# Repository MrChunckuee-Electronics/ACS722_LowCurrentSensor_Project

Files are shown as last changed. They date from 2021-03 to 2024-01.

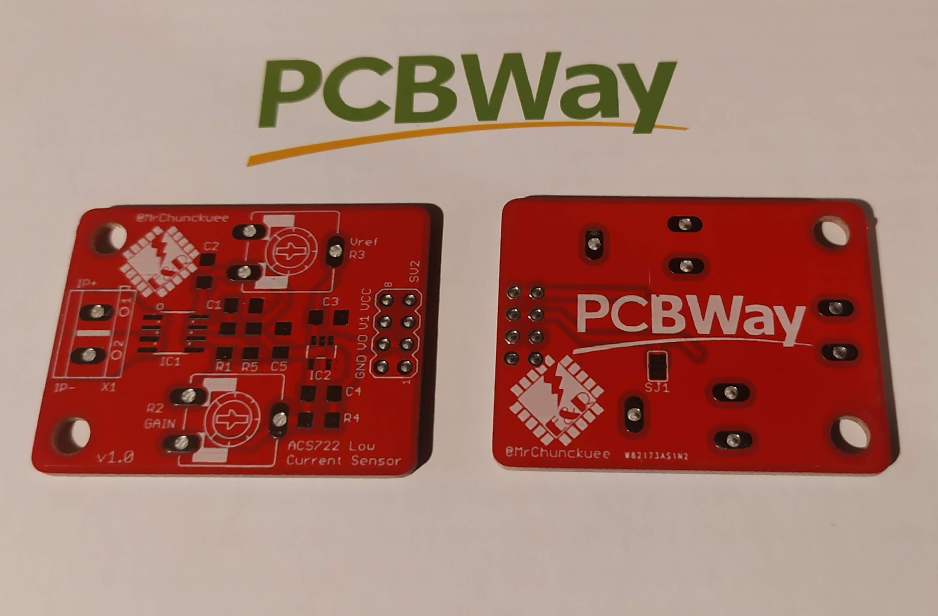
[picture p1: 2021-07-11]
assets/6 ACS722_Low_Current_Sensor_Photo1.jpg

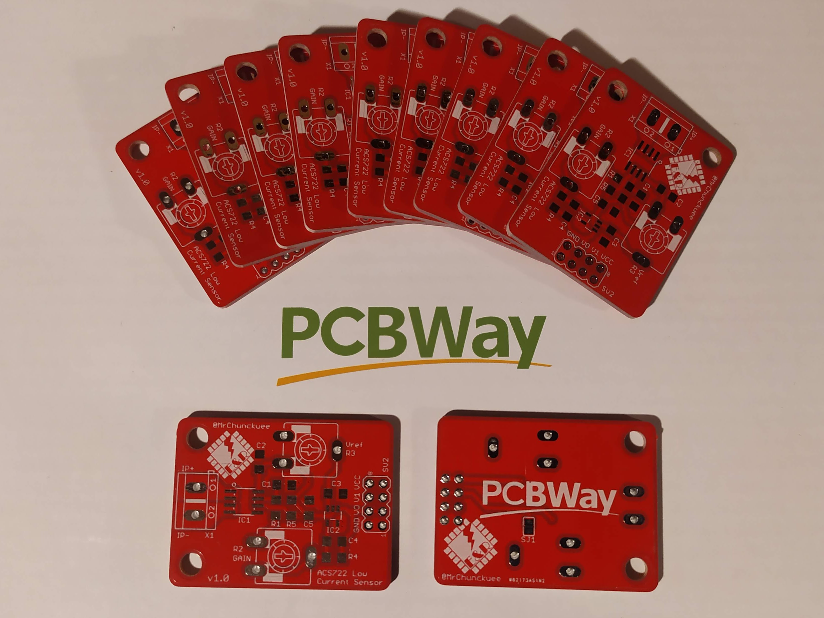
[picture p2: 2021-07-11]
assets/7 ACS722_Low_Current_Sensor_Photo2.jpg

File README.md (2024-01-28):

# ACS722 Low Current Sensor Project

***
Puedes seguirme en:
- [Blogspot](http://mrchunckuee.blogspot.com)
- [Instagram](https://www.instagram.com/mrchunckuee_electronics/)
- [Facebook](https://www.facebook.com/MrChunckueeElectronics)
- [Twitter](https://twitter.com/MrChunckuee)
- [YouTube](https://www.youtube.com/@MrChunckueeElectronics)

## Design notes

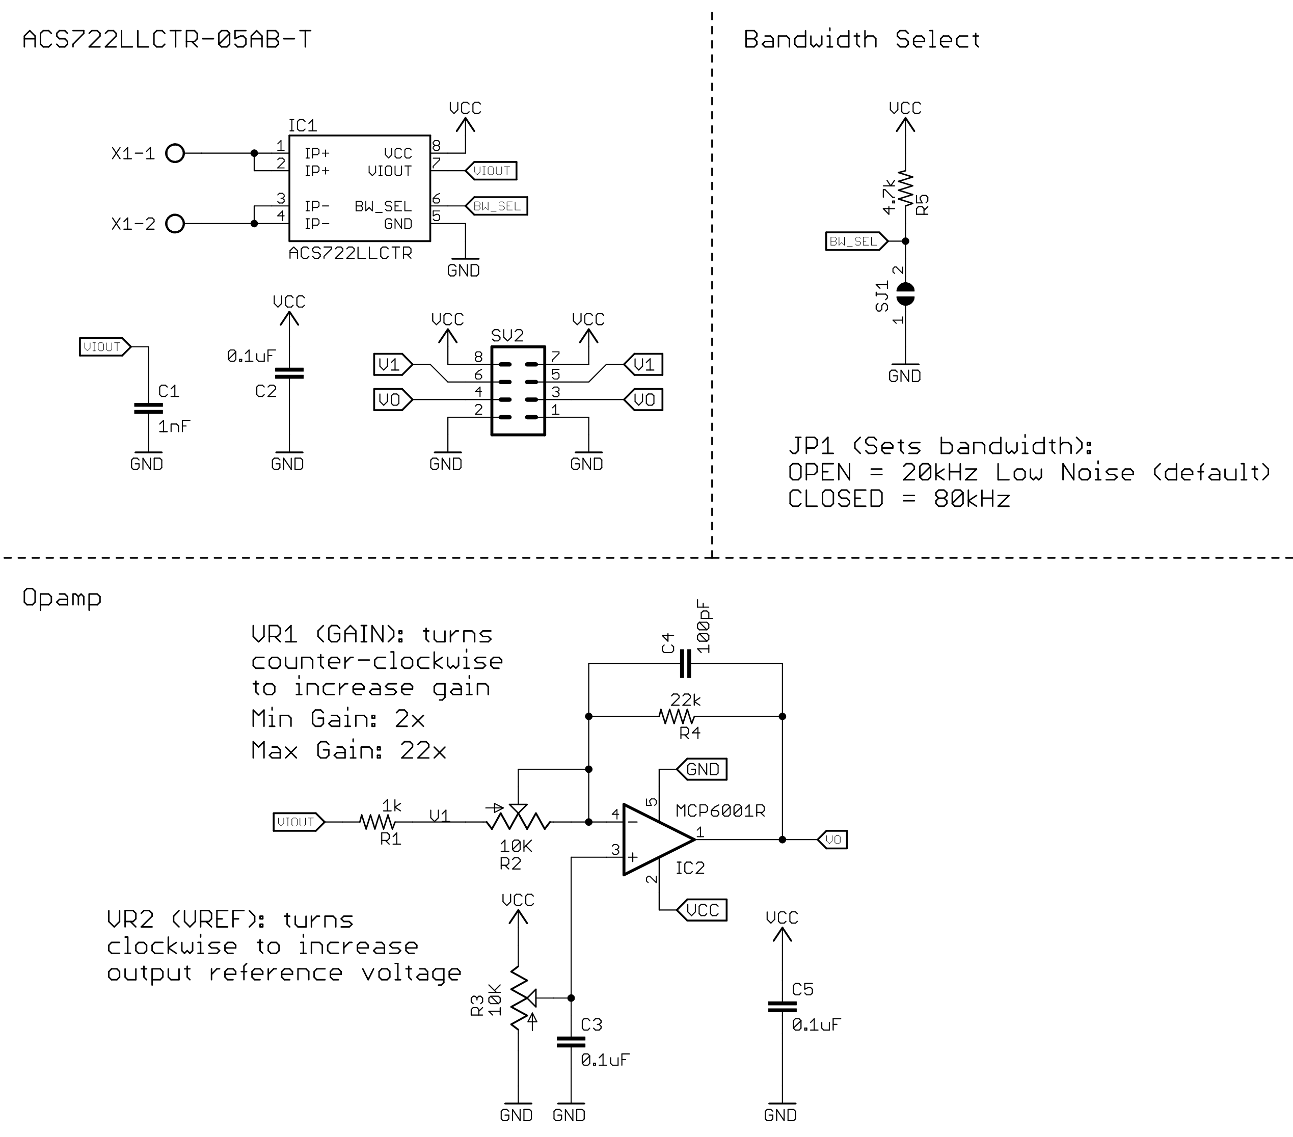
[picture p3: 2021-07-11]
assets/0 ACS722_Low_Current_Sensor_Schematic.png

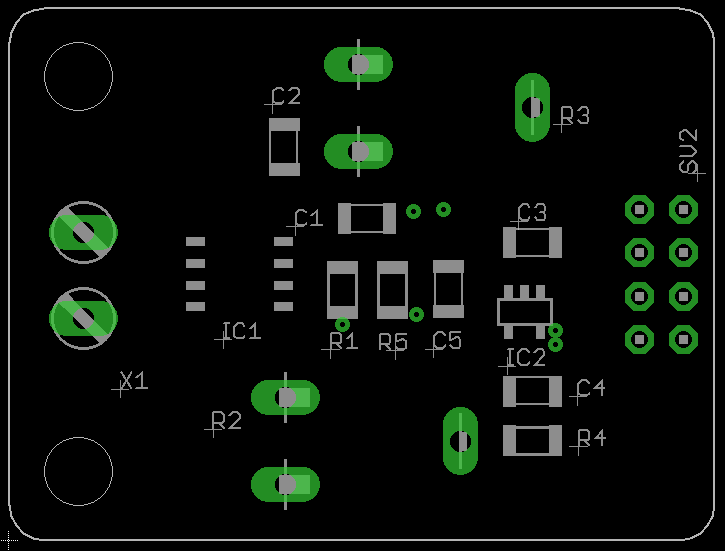
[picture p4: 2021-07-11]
assets/4 ACS722_Low_Current_Sensor_Serigrafia_Top.PNG

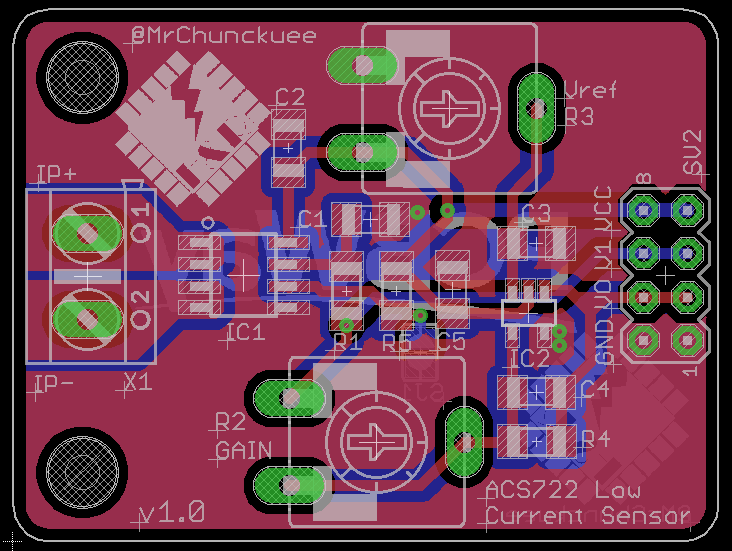
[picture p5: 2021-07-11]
assets/1 ACS722_Low_Current_Sensor_all.PNG

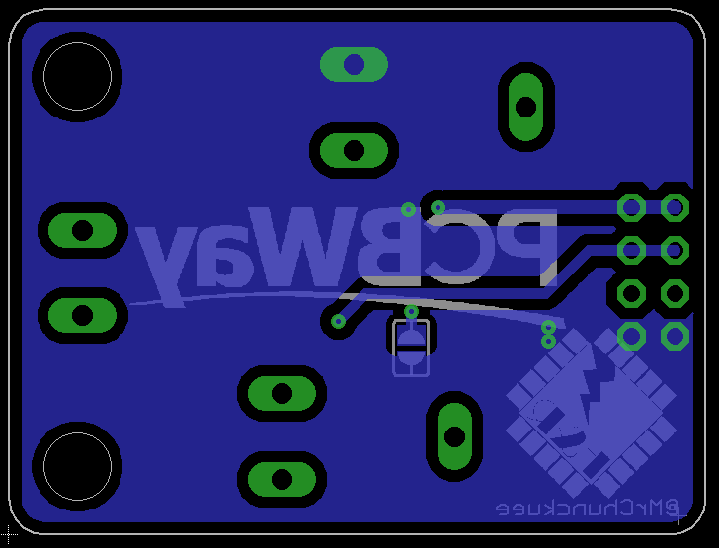
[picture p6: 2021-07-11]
assets/3 ACS722_Low_Current_Sensor_Bottom.PNG

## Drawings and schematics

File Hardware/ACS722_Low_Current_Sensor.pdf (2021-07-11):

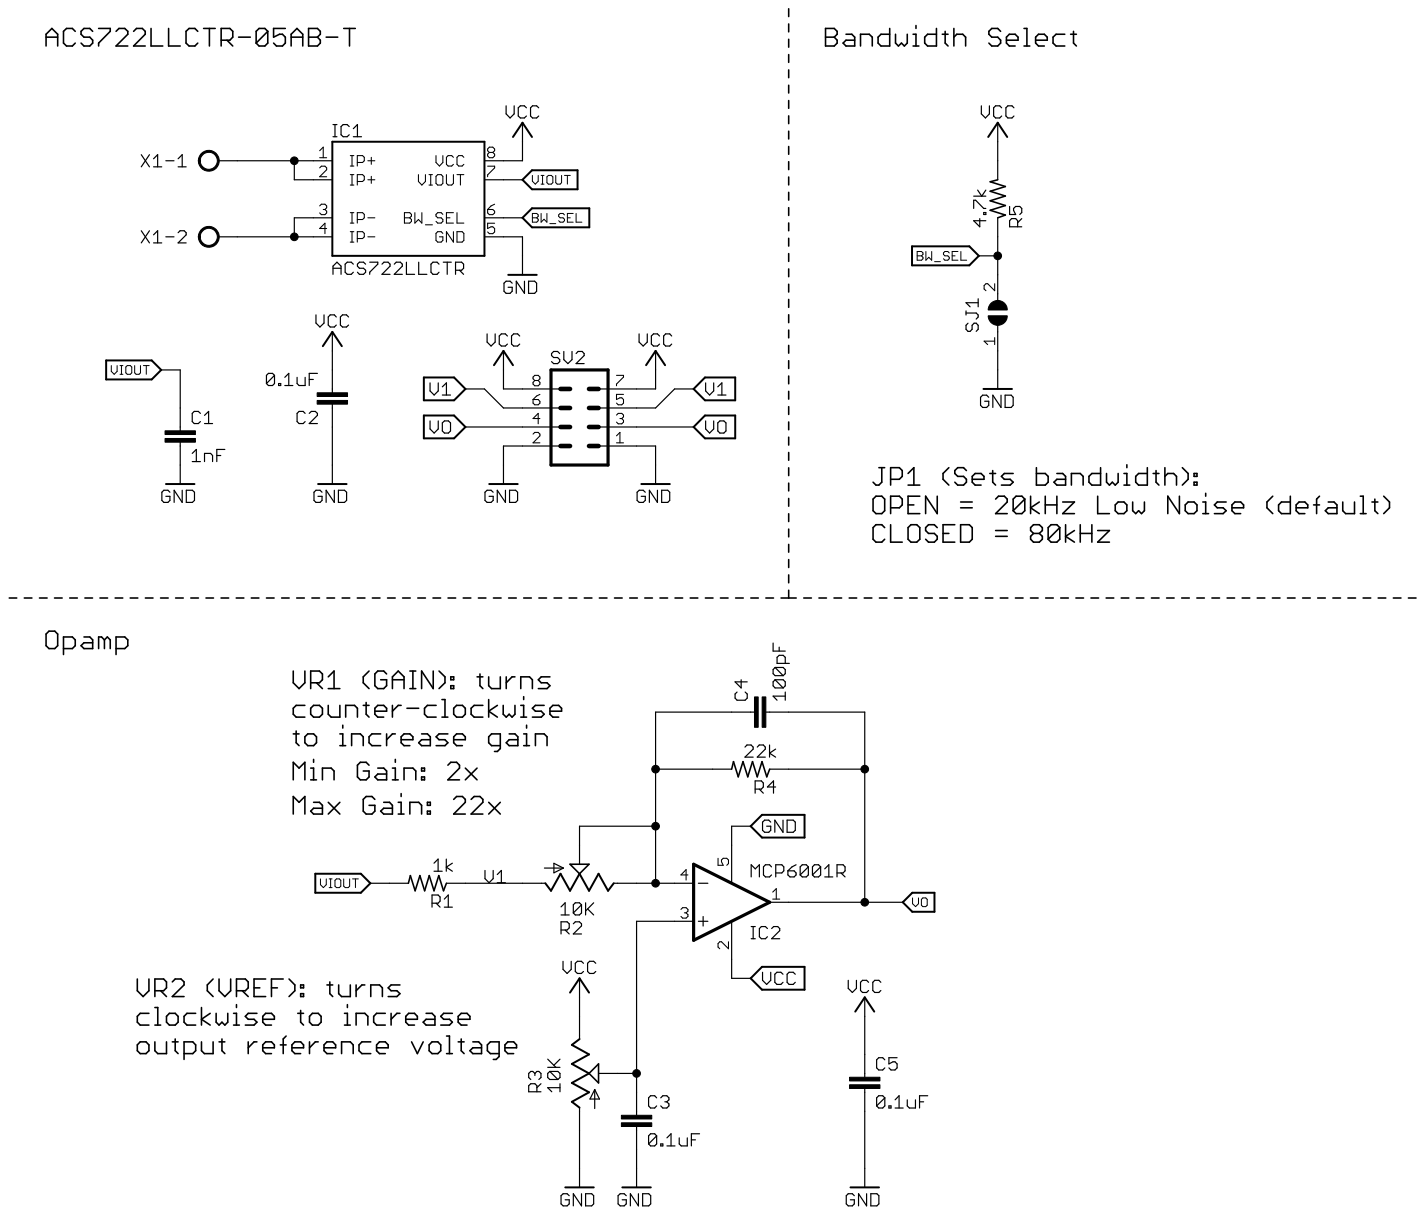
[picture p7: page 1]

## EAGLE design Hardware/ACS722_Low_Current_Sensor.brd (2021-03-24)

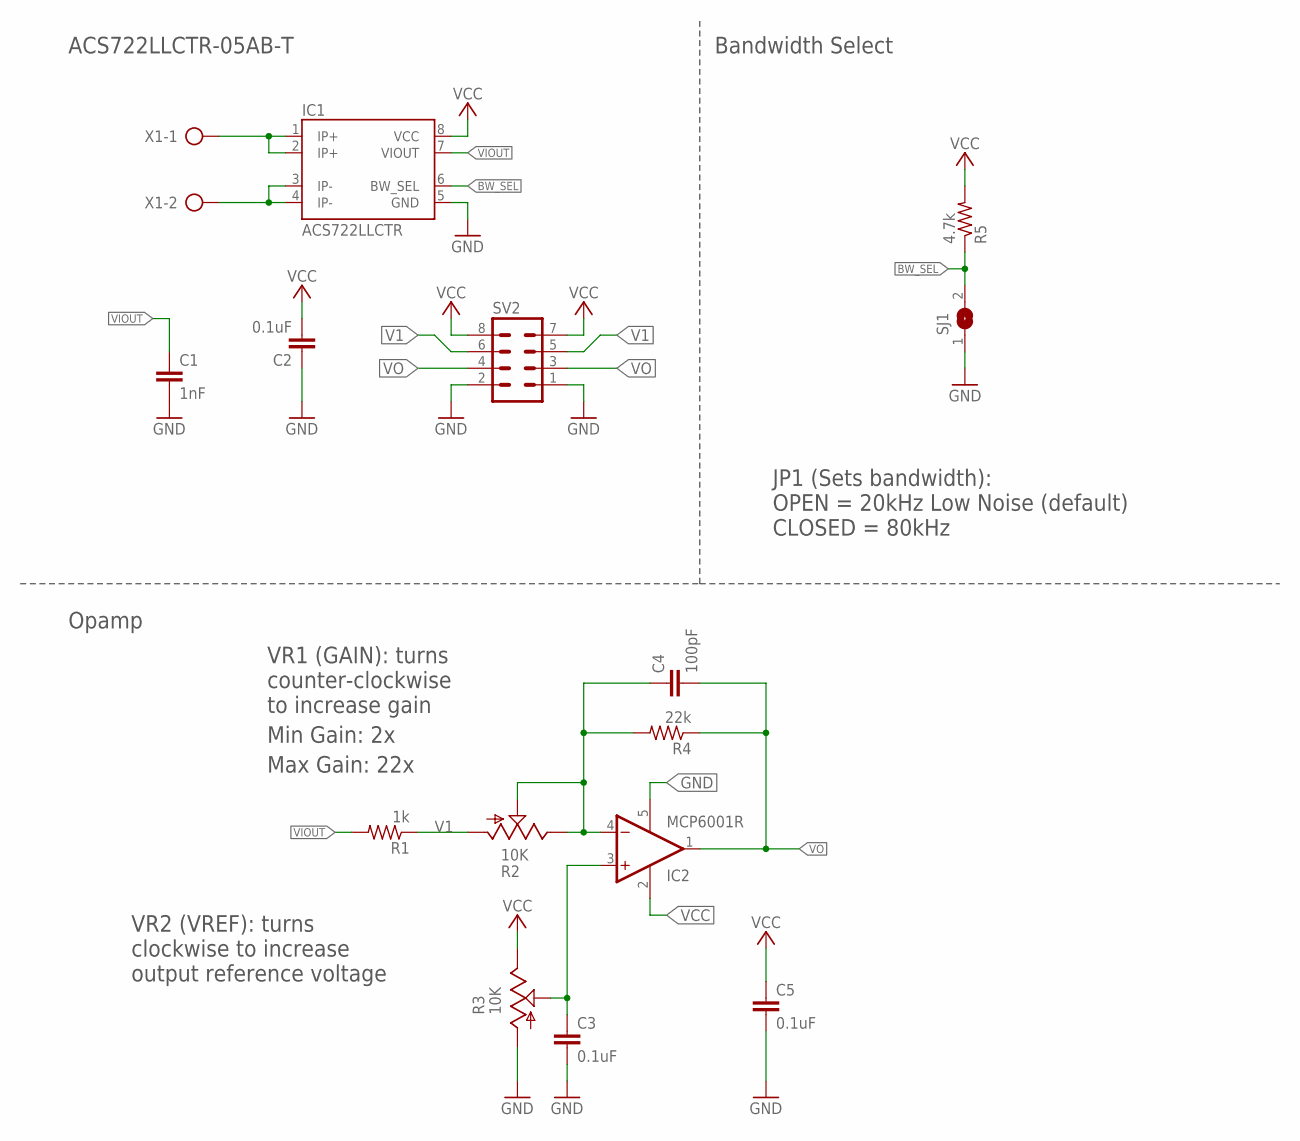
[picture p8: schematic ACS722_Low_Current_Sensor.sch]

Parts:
C1: 1nF; C1206
C2, C3, C5: 0.1uF; C1206
C4: 100pF; C1206
IC1: ACS722LLCTR; SO-08
IC2: MCP6001R; SOT23-5
R1: 1k; R1206
R2, R3: 10K; CA9V
R4: 22k; R1206
R5: 4.7k; R1206
SJ1: SJ
SV2: MA04-2
X1: AK500/2

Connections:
BW_SEL: IC1.6 (BW_SEL), R5.1, SJ1.2
GND: C1.2, C2.1, C3.2, C5.2, IC1.5 (GND), IC2.5 (V-), R3.A, SJ1.1, SV2.1, SV2.2
IP+: IC1.1 (IP+), IC1.2 (IP+), X1.1
IP-: IC1.3 (IP-), IC1.4 (IP-), X1.2
unnamed: C4.1, IC2.4 (-IN), R2.E, R2.S, R4.2
unnamed: C3.1, IC2.3 (+IN), R3.S
V1: R1.1, R2.A, SV2.5, SV2.6
VCC: C2.2, C5.1, IC1.8 (VCC), IC2.2 (V+), R3.E, R5.2, SV2.7, SV2.8
VIOUT: C1.1, IC1.7 (VIOUT), R1.2
VO: C4.2, IC2.1 (OUT), R4.1, SV2.3, SV2.4

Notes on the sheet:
Opamp
JP1 (Sets bandwidth):
CLOSED = 80kHz
OPEN = 20kHz Low Noise (default)
Bandwidth Select
VR1 (GAIN): turns counter-clockwise to increase gain
VR2 (VREF): turns clockwise to increase output reference voltage
ACS722LLCTR-05AB-T
Max Gain: 22x
Min Gain: 2x

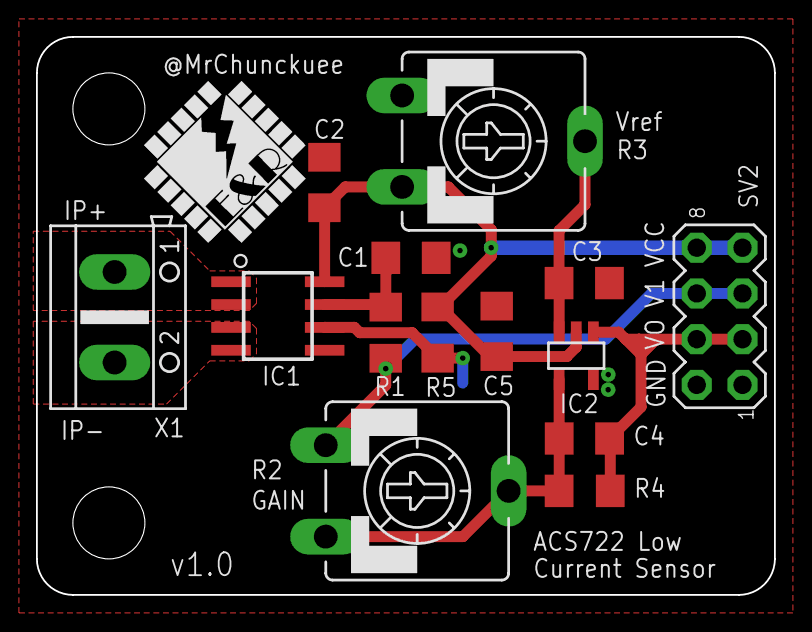
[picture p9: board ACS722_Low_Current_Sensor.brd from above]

Board: 2 copper layers, 41.0 x 31.0 mm, 15 parts (1 on the bottom side), 10 nets.

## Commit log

2021-03-24 Created project
    [ACS722_Low_Current_Sensor.brd, ACS722_Low_Current_Sensor.sch]
2021-03-24 Add GERBERs
    [ACS722_Low_Current_Sensor.drl]
2021-03-24 Respaldo GERBERs del HW v1.0
2021-03-24 Creación del hardware ACS22 Low Current Sensor v1.0
    [ACS722_Low_Current_Sensor.brd, ACS722_Low_Current_Sensor.sch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]
